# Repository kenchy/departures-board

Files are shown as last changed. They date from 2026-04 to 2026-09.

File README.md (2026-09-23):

# departures-board 

This is an ESP32 based Departures Board replicating those at many UK railway stations (using data provided by National Rail's public API), London Underground Arrivals boards (using data provided by TfL) and UK wide bus stops (using data provided by bustimes.org). This implementation uses a 3.12" OLED display panel with SSD1322 display controller onboard, plus an optional TTP223 touch sensor. STL files are also provided for 3D printing the custom desktop case. Pre-assembled departure boards are also available exclusively from our [store](https://store.gadec.co.uk).


A larger LED Matrix version of this project, with audio station announcements, is also available [here](https://github.com/gadec-uk/matrix-departures-board).

A model railway (00 gauge) version of this project is also available [here](https://github.com/gadec-uk/tiny-departures-board).

## Features
* All processing is done onboard by the ESP32 processor, no middleware servers
* Support for touch sensor to switch modes / stations / wake from screensaver
* Smooth animation matching the real departures and arrivals boards
* Displays up to the next 9 departures with scheduled time, platform number, destination, calling stations and expected departure time
* Optionally display the last reported location of a service
* Optionally only show services calling at a selected railway station
* Scheduler and Carousel modes to automatically switch between any combination of railway, tube and bus stops
* Displays Network Rail service messages
* Train information (operator, class, number of coaches etc.)
* Displays up to the next 9 arrivals with time to station (London Underground mode)
* Optionally display the current location of the train (London Underground mode)
* TfL station and network service messages (London Underground mode)
* Optionally filter by tube line and direction
* In Bus mode, displays up to the next 9 departures with service number, destination, vehicle registration and schedule/expected time
* Optionally display RSS headline feeds with UK news, sports and rail news
* RSS Feed Editor to add custom headline feeds
* Fully-featured browser based configuration screens - choose any station on the UK network / London Tube & DLR network / UK Bus Stops
* Automatic firmware updates (optional)
* Displays the weather at the selected location (optional)
* Full-screen, Network SouthEast style station clock (optional)
* STL files provided for custom 3D printed case



## Quick Start

### What you'll need

1. An ESP32 D1 Mini board (or clone) - either USB-C or Micro-USB version with CH9102 recommended. For example, from [AliExpress](https://www.aliexpress.com/item/1005005972627549.html).
2. A 3.12" 256x64 OLED Display Panel with SSD1322 display controller onboard. For example, from [AliExpress](https://www.aliexpress.com/item/1005008558326731.html).
3. A 3D printed case using the [STL](https://github.com/gadec-uk/departures-board/tree/main/stl) files provided. If you don't have a 3D printer, you can use a 3D print service, local library or group.
4. Optionally, a TTP223 touch sensor (for easily switching modes / stations). For example, from [AliExpress](https://www.aliexpress.com/item/1005007850732859.html). If fitted, the touch sensor should be glued to the inside of one of the walls of the top part of the case with the *sensor* side against the case.
5. For National Rail, the board supports using either the Rail Delivery Group feeds (recommended) or the legacy OpenLDBWS feed. Both feeds are free of charge and provide identical information but the legacy OpenLDBWS feed may be discontinued in the future. To use the Rail Delivery Group feeds, you will need a [Live Departure Board 1.1](https://raildata.org.uk/dataProduct/P-d81d6eaf-8060-4467-a339-1c833e50cbbe/overview) consumer key and (optionally) a [Service Details 1.1](https://raildata.org.uk/dataProduct/P-4dec1247-d040-4290-80a4-639dfac54a92/overview) consumer key. Alternatively, if you prefer to use the legacy OpenLDBWS feed, you can register for a token [here](https://realtime.nationalrail.co.uk/OpenLDBWSRegistration).
6. By default, weather data is sourced from Open-Meteo. If you prefer to use OpenWeather (which usually provides slightly more localised weather conditions) you will need an OpenWeather Map API token (these are also free, sign-up for a free developer account [here](https://home.openweathermap.org/users/sign_up)).
7. Some intermediate soldering skills.

A step-by-step guide to obtaining the API keys is available [here](https://departures-board.github.io/Departures-Board-API-Keys-Guide.pdf).



### Preparing the OLED display for 4-Wire SPI Mode


As supplied, the display is usually shipped with 8-bit 80XX mode enabled. This needs to be changed to 4-Wire SPI mode by removing one link and adding another (the image shows where to make these changes on the rear of the circuit board).

### Wiring Guide

Solder the 4 SPI connections, plus power and ground. The wires **MUST** be soldered to the **BACK** of the ESP32 Mini board (the side without the components) to enable it to sit in place in the case. You can solder directly to the pins on the OLED screen or for the best fit (if you are a more experienced solderer) de-solder and remove the header pins and solder directly to the board. You cannot use Dupont connectors, they will not fit the custom case design.

| OLED Pin | ESP32 Mini Pin |
|:---|:---:|
| 1 VSS | GND |
| 2 VCC_IN | 3.3v |
| 4 D0/CLK | IO18 |
| 5 D1/DIN | IO23 |
| 14 D/C# | IO5 |
| 16 CS# | IO26 |

| TTP223 Pin | ESP32 Mini Pin |
|:---|:---:|
| 1 GND | GND |
| 2 I/O | IO34 |
| 3 VCC | 3.3v |



### Installing the firmware

The project uses the Arduino framework and the ESP32 v3.3.9 core. If you want to build from source, you'll need [PlatformIO](https://platformio.org). The software is designed for, and makes use of, a dual-core ESP32 processor. If you attempt to target and compile for a single core ESP32 variant the experience will be suboptimal at best.

The easiest way to install the firmware for the first time is to use the online web based installer [here](https://departures-board.github.io). You will need to use Chrome, Edge or Firefox as your browser as Safari does not support Web Serial.

Alternatively, you can download pre-compiled firmware images from the [releases](https://github.com/gadec-uk/departures-board/releases). These can be installed over the USB serial connection using [esptool](https://github.com/espressif/esptool). If you have python installed, install with *pip install esptool*. For convenience, a pre-compiled executable version for Windows is included [here](https://github.com/gadec-uk/departures-board/tree/main/esptool).

If the board is not recognised you are probably using a version with the CP2104 USB-to-Serial chip. Drivers for the CP2104 are [here](https://www.silabs.com/developer-tools/usb-to-uart-bridge-vcp-drivers?tab=downloads)

Attach the ESP32 Mini board via it's USB port and use the following command to flash the firmware:

```
esptool.py --chip esp32 --baud 460800 write_flash -z \
  0x1000 bootloader.bin \
  0xe000 boot_app0.bin \
  0x8000 partitions.bin \
  0x10000 firmware.bin
```

The tool should automatically find the correct serial port. If it fails to, you can manually specify the correct port by adding *--port COMx* (replace *COMx* with your actual port, e.g. COM3, /dev/ttyUSB0, etc.).

If using the pre-compiled esptool.exe version on Windows, save the esptool.exe and the four firmware (.bin) files to the same directory. Open a command prompt (Windows Key + R, type cmd and press enter) and change to the directory you saved the files into. Now type the following command on one line and press enter:
```
.\esptool --chip esp32 --baud 460800 write_flash -z 0x1000 bootloader.bin 0xe000 boot_app0.bin 0x8000 partitions.bin 0x10000 firmware.bin
```

Subsequent updates can be carried out automatically over-the-air or you can manually update from the Web GUI.

### First time configuration

WiFiManager is used to setup the initial WiFi connection on first boot. The ESP32 will broadcast a temporary WiFi network named "Departures Board", connect to the network and follow the on-screen instructions. You can also watch a video walk-through of setup and configuration process below (this video shows an earlier version of the firmware, but the process is the same).
Departures Board Setup Video (https://youtu.be/PZVyE_SoLBU)

Once the ESP32 has established an Internet connection, the next step is to enter your API keys (if you do not enter a National Rail token, the board will only operate in Tube and Bus modes). Finally, select a station location. Start typing the location name and valid choices will be displayed as you type.

### Web GUI

At start-up, the ESP32's IP address is displayed. To change the station or to configure other miscellaneous settings, open the web page at that address. The settings available are:
- **Board Mode** - switch between National Rail Departures, London Underground Arrivals or UK Bus Stops modes.
- **Station** - start typing a few characters of a station name and select from the drop-down station picker displayed (National Rail mode).
- **Only show services calling at** - filter services based on *calling at* location (National Rail mode - if you want to see the next trains *to* a particular station).
- **Only show these platforms** - filter services based on the platform they depart from. Note: there are many services for which platform number is not supplied, these would also be filtered out.
- **Add to Scheduler** - adds the current configured station/tube/bus stop to the scheduler (see schedule tab) to switch based on time of day.
- **Add to Carousel** - adds the current configured station/tube/bus stop to the carousel (see schedule tab) to switch views after a period of time.
- **Underground Station** - start typing a few characters of an Underground or DLR station name and select from the drop-down station picker displayed (London Underground mode).
- **Filter by Line** - select the desired underground line or all lines for all arrivals.
- **Filter by Direction** - select the desired direction or any direction for all arrivals.
- **Bus Stop ATCO code** - type the ATCO number of the bus stop you want to monitor (see [below](#bus-stop-atco-codes) for details).
- **Only show these Bus services** - filter buses by service numbers (enter a list of the service numbers, comma separated).
- **Recently verified ATCO codes** - quickly select from recently used bus stop ATCO codes.
#### Options tab ####
- **Brightness** - adjusts the brightness of the OLED screen.
- **Show the date on screen** - displays the date in the upper-right corner (useful if you're also using this as a desk clock).
- **Show current weather at station/bus stop** - optionally display weather conditions at the selected station or bus stop.
- **Include bus replacement services** - optionally include bus replacement services (National Rail mode).
- **Show station messages** - displays station and service messages (Rail and Tube modes).
- **Show service location** - displays the current location of the next tube train that is due to arrive (Tube mode).
- **Show platform numbers if available** - deselecting this option will hide platform numbers (National Rail).
- **Show service ordinal numbers** - displays "2nd","3rd","4th" etc. next to the service times (National Rail).
- **Show service last seen location** - adds the last reported location and time of a service to the Calling at list (National Rail).
- **Wait for Calling at list to complete** - waits for the Calling at list to finish scrolling before changing the primary service.
- **Wait for Messages or RSS to complete** - waits for the current service message or RSS headline feed to finish scrolling before changing the primary service.
- **Full screen clock if no train services** - displays the full screen, Network SouthEast style station clock if there are no scheduled services at the selected railway station.
- **Enable automatic firmware updates at startup** - automatically checks for AND installs the latest firmware from this repository when the system starts up.
- **Enable daily check for firmware updates** - when enabled, the system will check for and install any updates just after midnight if the board is powered on.
- **Enable overnight sleep mode (screensaver)** - if you're running the board 24/7, you can help prevent screen burn-in by enabling this option overnight.
- **Switch off display during sleep mode** - turns off the display completely during sleep mode, otherwise displays the date & time.
- **Full screen clock during sleep mode** - displays the full screen station clock during sleep mode.
#### Schedule tab ####
- **Enable scheduler** - automatically switches between views based on the configured time of each entry in the scheduler list below.
- **Enable carousel** - automatically switches between views based on the configured view time of each entry in the carousel list below.
#### Advanced Tab ####
- **Enable touch sensor** - a tap switches between configured modes (rail/tube/bus) or wakes from sleep. If the Scheduler or Carousel mode is active, a tap switch to the next location in the list. Obviously, do not enable this option if you have not installed a TTP223 touch sensor.
- **Wake from sleep by touch for** - if the board is in screensaver mode and the touch sensor is enabled, a tap will wake the board and it will remain awake for the selected number of minutes (the countdown timer resets on each tap).
- **Long press displays full screen clock** - a long tap switches to the full screen station clock. A short tap will revert to normal operation.
- **Flip the display 180°** - Rotates the display (the case design provides two different viewing angles depending on orientation).
- **Set custom hostname for this board** - change the hostname from the default "DeparturesBoard", useful if you are running multiple boards.
- **Custom (non-UK) time zone (only for clock)** - if you're not based in the UK you can set the clock to display in your local time zone (see [below](#custom-time-zones) for details).
- **Suppress calling at / information messages** - removes all horizontally scrolling text (much lower functionality but less distracting).
- **Increase API refresh rate** - Reduces the interval between data refreshes (National Rail mode).
- **Display RSS news headlines feed** - Displays the top headlines from the selected feed (Rail/Tube mode).
- **Prioritise RSS headlines feed** - Displays headlines before other network service messages.
- **Display departures offset by** - Displays future (or past) services offset by the selected time. This does not affect the clock display (Rail mode).
- **Rail data source** - Select which api feed should be used for National Rail mode (only feeds with api keys present are shown).

A drop-down menu (top-right) adds the following options:
- **Check for Updates** - manually checks for and optionally installs any updates to the firmware. Also displays the release notes of the latest firmware.
- **Edit API Keys** - view/edit your National Rail, OpenWeather Map and Transport for London API keys.
- **Edit RSS Feeds** - loads the RSS Feeds Editor where you can add/edit/delete custom headline feeds.
- **Clear WiFi Settings** - deletes the stored WiFi credentials and restarts in WiFiManager mode (useful to change WiFi network).
- **Restart System** - restarts the ESP32.

#### Other Web GUI Endpoints

A few other urls have been implemented, primarily for debugging/developer use:
- **/factoryreset** - deletes all configuration information, api keys and WiFi credentials. The entire setup process will need to be repeated.
- **/update** - for manual firmware updates. Download the latest binary from the [releases](https://github.com/gadec-uk/departures-board/releases). Only the **firmware.bin** file should be uploaded via */update*. The other .bin files are not used for upgrades. This method is *not* recommended for normal use.
- **/info** - displays some basic information about the current running state.
- **/formatffs** - formats the filing system, erasing the configuration files (but not the WiFi credentials).
- **/dir** - displays a (basic) directory listing of the file system with the ability to view/delete files.
- **/upload** - upload a file to the file system.
- **/control** - an endpoint for automation of sleep mode. Takes optional parameters *sleep* and *clock* - e.g. /control?sleep=1&clock=0 will force sleep mode and turn off the display completely. /control?sleep=0 will revert to normal operation. Always returns current state as json.

### Bus Stop ATCO codes
Every UK bus stop has a unique ATCO code number. To find the ATCO code of the stop you want to monitor, go to [bustimes.org/search](https://bustimes.org/search) and type a location in the search box. Select the location from the list of places shown and then select the particular stop you want from the list. The ATCO code is shown on the stop information page. After entering the code in the Departures Board setup screen, tap the **Verify** button and the location will be shown confirming your selection. You must use the **Verify** button *before* you can save changes. Up to ten of the most recently verified ATCO codes are saved and can be selected from a dropdown list for quick access. The bustimes map and search facility are also embedded in the Bus mode configuration screen from firmware B2.3 onwards.



### Custom Time Zones
To set a custom time zone for the departure board clock, you will need to enter the POSIX time zone string for your location. Some examples are `CST6CDT,M3.2.0/2,M11.1.0/2` for Canada (Central Time) and `AEST-10AEDT,M10.1.0,M4.1.0/3` for Australia (Eastern Time). The easiest way to find the correct syntax is to ask your favourite AI chat engine *"What is the POSIX time zone string for ..."*. Note that changing the time zone only affects the clock (and date) display. Service times are *always* shown in UK time.

### Donating


This software is completely free for non-commercial use without obligation. If you would like to support me and encourage ongoing updates, you can [buy me a coffee!](https://buymeacoffee.com/gadec.uk)

### Licence
This work is licensed under **Creative Commons Attribution-NonCommercial-ShareAlike 4.0**. To view a copy of this licence, visit [https://creativecommons.org/licenses/by-nc-sa/4.0/](https://creativecommons.org/licenses/by-nc-sa/4.0/). Note: the terms of the licence prohibit commercial use of this work, this includes *any* reselling of the work in kit or assembled form for commercial gain.

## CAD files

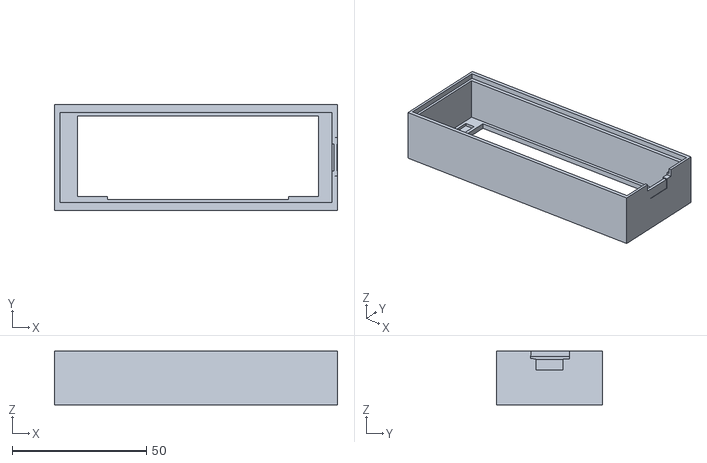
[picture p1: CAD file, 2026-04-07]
stl/Departures Board OLED Case Top Supermini.stl
105.5 x 39.7 x 20.0

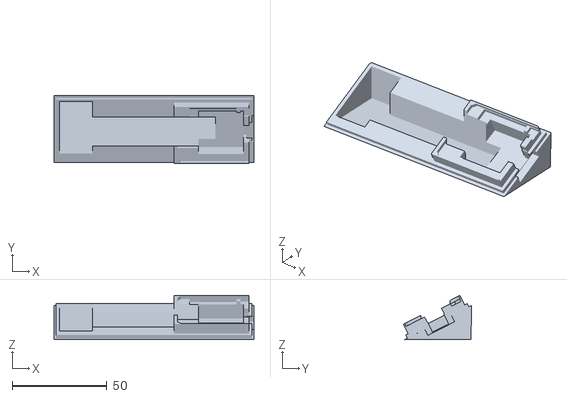
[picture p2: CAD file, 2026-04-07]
stl/Departures Board OLED Case Bottom Supermini.stl
105.5 x 36.1 x 23.4

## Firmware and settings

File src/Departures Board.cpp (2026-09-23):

/*
 * Departures Board (c) 2025-2026 Gadec Software
 *
 * https://github.com/gadec-uk/departures-board
 *
 * This work is licensed under Creative Commons Attribution-NonCommercial-ShareAlike 4.0 International.
 * To view a copy of this license, visit https://creativecommons.org/licenses/by-nc-sa/4.0/
 *
 * ESP32 "Mini" Board with 3.12" 256x64 OLED Display Panel with SSD1322 controller on-board.
 *
 * OLED PANEL     ESP32 MINI
 * 1 VSS          GND
 * 2 VCC_IN       3.3V
 * 4 D0/CLK       IO18
 * 5 D1/DIN       IO23
 * 14 D/C#        IO5
 * 16 CS#         IO26
 *
 * Optional TTP223 touch sensor connection:
 *
 * TTP223         ESP32 MINI
 * GND            GND
 * VCC            3.3V
 * I/O            IO34
 *
 */

#include <Arduino.h>
#include <WiFi.h>
#include <WiFiClientSecure.h>
#include <WiFiManager.h>
#include <AsyncTCP.h>
#include <ESPAsyncWebServer.h>
#include <StreamString.h>
#include <Ticker.h>
#include <HTTPClient.h>
#include <ESPmDNS.h>
#include <HTTPUpdateGitHub.h>
#include <FS.h>
#include <LittleFS.h>
#include <ArduinoJson.h>
#include <weatherClient.h>
#include <sharedDataStructs.h>
#include <responseCodes.h>
#include <raildataXmlClient.h>
#include <rdmRailClient.h>
#include <TfLdataClient.h>
#include <busDataClient.h>
#include <githubClient.h>
#include <rssClient.h>
#include <touchSensor.h>
#include <webgui/webgraphics.h>
#include <webgui/index.h>
#include <webgui/keys.h>
#include <webgui/editrss.h>
#include <webgui/rss.h>
#include <gfx/xbmgfx.h>
#include <time.h>

#include <SPI.h>
#include <U8g2lib.h>

#define msDay 86400000 // 86400000 milliseconds in a day
#define msHour 3600000 // 3600000 milliseconds in an hour
#define msMin 60000 // 60000 milliseconds in a second

static AsyncWebServer server(80); // Hosting the Web GUI

// Shorthand for response formats
static const char contentTypeJson[] = "application/json";
static const char contentTypeText[] = "text/plain";
static const char contentTypeHtml[] = "text/html";

// Using NTP to set and maintain the clock
static struct tm timeinfo;
static const char ukTimezone[] = "GMT0BST,M3.5.0/1,M10.5.0";

// Default hostname
static const char defaultHostname[] = "DeparturesBoard";

// Local firmware updates via /update Web GUI
static const char updatePage[] =
"<script src='https://ajax.googleapis.com/ajax/libs/jquery/3.2.1/jquery.min.js'></script>"
"<html><body style=\"font-family:Helvetica,Arial,sans-serif\"><h2>Departures Board Manual Update</h2><p>Upload a <b>firmware.bin</b> file.</p>"
"<form method='POST' action='#' enctype='multipart/form-data' id='upload_form'>"
   "<input type='file' name='update'>"
        "<input type='submit' value='Update'>"
    "</form>"
 "<div id='prg'>progress: 0%</div>"
 "<script>"
  "$('form').submit(function(e){"
  "e.preventDefault();"
  "var form = $('#upload_form')[0];"
  "var data = new FormData(form);"
  " $.ajax({"
  "url: '/update',"
  "type: 'POST',"
  "data: data,"
  "contentType: false,"
  "processData:false,"
  "xhr: function() {"
  "var xhr = new window.XMLHttpRequest();"
  "xhr.upload.addEventListener('progress', function(evt) {"
  "if (evt.lengthComputable) {"
  "var per = evt.loaded / evt.total;"
  "$('#prg').html('Progress: ' + Math.round(per*100) + '%');"
  "}"
  "}, false);"
  "return xhr;"
  "},"
  "success:function(d, s) {"
  "console.log('success!')"
 "},"
 "error: function (a, b, c) {"
 "}"
 "});"
 "});"
 "</script></body></html>";

// /upload page
static const char uploadPage[] =
"<html><body style=\"font-family:Helvetica,Arial,sans-serif\">"
"<h2>Upload a file to the file system</h2><form method='post' enctype='multipart/form-data'><input type='file' name='name'>"
"<input class='button' type='submit' value='Upload'></form></body></html>";

// /success page
static const char successPage[] =
"<html><body style=\"font-family:Helvetica,Arial,sans-serif\"><h3>Upload completed successfully.</h3>\n"
"<p><a href=\"/dir\">List file system directory</a></p>\n"
"<h2>Upload another file</h2><form method=\"post\" action=\"/upload\" enctype=\"multipart/form-data\"><input type=\"file\" name=\"name\"><input class=\"button\" type=\"submit\" value=\"Upload\"></form>\n"
"</body></html>";

#define SCREEN_WIDTH 256 // OLED display width, in pixels
#define SCREEN_HEIGHT 64 // OLED display height, in pixels
#define DIMMED_BRIGHTNESS 1 // OLED display brightness level when in sleep/screensaver mode

//U8G2_SSD1322_NHD_256X64_F_4W_HW_SPI u8g2(U8G2_R0, /* cs=*/ GPIO_NUM_26, /* dc=*/ GPIO_NUM_5, /* reset=*/ U8X8_PIN_NONE);
U8G2_SSD1322_NHD_256X64_F_4W_HW_SPI u8g2(U8G2_R0, /* cs=*/ 8, /* dc=*/ 9, /* reset=*/ U8X8_PIN_NONE);

// Vertical line positions on the OLED display (National Rail)
#define LINE0 0
#define LINE1 13
#define LINE2 28
#define LINE3 41
#define LINE4 55

// Vertical line positions on the OLED display (Underground)
#define ULINE0 0
#define ULINE1 15
#define ULINE2 28
#define ULINE3 41
#define ULINE4 56

static Ticker restartTimer; // used to schedule reboots

//
// Custom fonts - replicas of those used on the real display boards
//
static const uint8_t NatRailSmall9[1329] U8G2_FONT_SECTION("NatRailSmall9") =
  "\221\0\3\2\4\4\4\5\5\11\11\0\0\11\0\11\2\1E\2\214\5\30 \5\0\230)!\7q("
  "%\6%\42\10\63h)\22K\0#\17u(mJI\62(\225A)%\11\0$\14u(\255\262"
  "\245\266%\311\26\1%\14t(+\42E\212\244H\221\2&\16u(m\244\222\224$R\22EJ\0"
  "'\6\61h%\6(\11s(\251\222R\255\0)\11s()\262R\245\4*\12U\70-\222\312b"
  "Y\32+\12U\70\255\302h\220\302\10,\7\62\10g\22\5-\6\23X)\6.\6\21(%\2/"
  "\13t(\353\42)\222\42)\3\60\12u(m\226\314[\262\0\61\11s)m\22\251\313\0\62\13u"
  "(m\226,\314\332\6\1\63\14u(m\226,\214T-Y\0\64\15u(\355\62))%\203\26&"
  "\0\65\13u(-\216C\32j\311\2\66\15u(m\226L\34\222LK\26\0\67\12u(-\6\61"
  "+\66\1\70\15u(m\226LK\226LK\26\0\71\15u(m\226LK\206PK\26\0:\7A"
  "\70%\242\0;\7R(gR\5<\10t(\353\242\306\6=\10\64H+\206p\10>\11t(+"
  "\302\246\66\0?\14u(m\226,\214\264\34\212\0@\14u(m\226\314\222(C\272\0A\13u("
  "m\226L\33\206\314\26B\15u(-\206$\323\6%\323\6\5C\13u(m\226LlK\26\0D"
  "\13u(-\206$\363\66(\0E\13u(-\216\341\220\204\341 F\13u(-\216\341\220\204E\0"
  "G\15u(m\226LL\206LK\26\0H\13u(-\62\333\60d\266\0I\7q(%\16\1J"
  "\11u(-;j\311\2K\15u(-\62))iIT\311\2L\11u(-\302\36\7\1M\13"
  "u(-\262eI\64\267\0N\13u(-\262II\244\315\26O\12u(m\226\314[\262\0P\14"
  "u(-\206$\323\6%,\2Q\13\225\10m\226\314[\62\246\1R\15u(-\206$\323\6\245T"
  "\311\2S\13u(m\226L]\265d\1T\11u(-\6)\354\11U\11u(-\62\337\222\5V"
  "\12u(-\62oI-\2W\13u(-\62\227DIn\1X\14u(-\62-\251UjZ\0"
  "Y\13u(-\62-\251\205M\0Z\12u(-\6\61\353\70\10[\10r('\226.\2\134\12t"
  "(+\62-\323\62-]\10r(\63\224.\3^\6#xi\32_\7\24\30+\206\0`\7\42x"
  "'\242\0a\12U(m\326d\320\222!b\13u(-\302\212I\323\6\5c\11U(m\6\261:"
  "\4d\13u(-+\246MK\206\0e\12U(m\226l\30\322!f\12t(\253*\245)+\1"
  "g\14u\10m\6\315\226\14\341\240\0h\12u(-\302\212I\263\5i\7q(%\222Aj\13\224"
  "\10\353r k\223\22\5k\13t(+\262\222\222HI)l\7q(%\16\1m\12U(m\272"
  "(\211\246\5n\11U(-\22\223f\13o\12U(m\226\314\226,\0p\14u\10-\206$\263\15"
  "J\30\2q\13u\10m\6\315\226\14a\1r\11U(-\22\223X\4s\11U(m\6\365\240\0"
  "t\13t(k\262hH\262\242\0u\11U(-\62'E\11v\12U(-\62[R\213\0w\14"
  "U(-\62%Q\22\245\13\0x\12U(-\262\244V\251\5y\13u\10-\62\267d\10\7\5z"
  "\11U(-\6\255m\20{\12s(\251\222(\311\242,|\7q(%\16\1}\13s()\262("
  "K\242$\2~\10%XmL\11\0\15u(-\222\254R\214\222(Q\12\200\5\0\10!\201\14"
  "e)\361\222A\213\262A\311\0\202\10B\10g*\12\0\203\5\0\10!\204\11D\10kzQ\22\0"
  "\205\7\25(-\222\2\206\15v(o\206$\64\16\17I\224\0\207\16w(\261\266\244)\262\250I\226"
  "M\0\210\21\210\30\63\323!\213\222d\213\262\245\224\15i\10\211\5\0\10!\212\5\0\10!\213\5\0"
  "\10!\214\5\0\10!\215\15u(/NK\242)C\62\14\2\216\16u(/\16\221\62(\203\42\15"
  "C\0\217\14w(\61\336\246\310\242n\303\1\220\6\63N?\36\221\7\62h'\222(\222\7\62hg"
  "\22\5\223\10\64h+\222\246$\224\10\64hkZ\224\4\225\6\63H)\36\226\7\25X-\6\1\227"
  "\5\0\10!\230\5\0\10!\231\5\0\10!\232\5\0\10!\233\5\0\10!\234\5\0\10!\235\5\0"
  "\10!\236\5\0\10!\237\5\0\10!\240\5\0\10!\241\5\0\10!\242\5\0\10!\243\14u(\255"
  "\244J\66Da\66\10\244\5\0\10!\245\5\0\10!\246\5\0\10!\247\5\0\10!\250\5\0\10!"
  "\251\5\0\10!\252\5\0\10!\253\5\0\10!\254\5\0\10!\255\5\0\10!\256\5\0\10!\257\5"
  "\0\10!\260\12DXk\224HJ\24\0\0\0\0";

static uint8_t NatRailTall12[1102] U8G2_FONT_SECTION("NatRailTall12") =
  "c\0\3\2\4\4\2\5\5\11\14\0\375\11\375\11\0\1Q\2\235\4\65 \5\0f\12!\7\221B"
  "\211C\22\42\7#^\212D\11#\21\225B\233R\222\14J)\211\222dPJI\2$\17\225B\253"
  "l)%\331\226DI\262E\0%\12\225B\313i\312:\35\1&\20\225B\33\251\22%Q$%\211"
  "\224D\221\22'\6!^\11\1(\11\223B\252\244\324\255\0)\11\223B\212\254\324\245\4*\14uF"
  "\253Je\261,M\21\0+\12UJ\253\60\32\244\60\2,\7\62\272\231D\1-\6\23R\212\1."
  "\6!B\11\1/\11\225B\313\266\216E\0\60\12\225B\233%\363[\262\0\61\11\223C\233D\352\313"
  "\0\62\13\225B\233%\13k\35\7\1\63\15\225B\233%\13Kj\250%\13\0\64\16\225B\273LJ"
  "JI\224\14ZX\1\65\15\225B\213c\70\244a\250%\13\0\66\15\225B\233%\23\303!\311l\311"
  "\2\67\15\225B\213A\254\205Y\230\205\31\0\70\15\225B\233%\263%KfK\26\0\71\15\225B\233"
  "%\263%C\30j\311\2:\6QJ\11E;\10b\306\231Z\242\0<\10t\306\272\250\261\1=\10"
  "\64\316\212!\34\2>\10t\306\212\260\251\15?\14\225B\233%\13k\305\34\212\0@\16\225B\233%"
  "\263$J\242\14a\272\0A\13\225B\233%\263\15C\346\26B\15\225B\213!\311l\203\222\331\6\5"
  "C\13\225B\233%\23{K\26\0D\13\225B\213!\311\374\66(\0E\13\225B\213cqH\302\342"
  " F\13\225B\213cqH\302F\0G\14\225B\233%\23K\233-Y\0H\13\225B\213\314m\30"
  "\62\267\0I\6\221B\211\7J\11\225B\313>j\311\2K\16\225B\213\60\223\222\222\246%Q%\13"
  "L\11\225B\213\260\37\7\1M\14\225B\213lY\22%\321\274\5N\15\225B\213l\232\224DI\244"
  "\233\26O\12\225B\233%\363[\262\0P\14\225B\213!\311l\203\22\66\2Q\13\265:\233%\363["
  "\62\246\1R\16\225B\213!\311l\203R\252dZ\0S\14\225B\233%S\325\242\226,\0T\11\225"
  "B\213A\12\373\11U\11\225B\213\314\337\222\5V\12\225B\213\314oI-\2W\13\225B\213\314\227"
  "DIn\1X\16\225B\213LKJIV\211\222\232\26Y\14\225B\213LKJI\26v\2Z\13"
  "\225B\213A\254u\14\7\1[\10\222\302\211\245/\2\134\11\225B\213\260\332\261\0]\10\222\302\11\245"
  "/\3^\6#^\232\6_\6\25>\213A`\6\42\336\211(a\13eB\233\65\31\64-\31\2b"
  "\14\225B\213\260\305\244i\223\242\0c\11eB\233Al\35\2d\13\225B\313\26\323fR\224\0e"
  "\14eB\233%\33\206\60K\26\0f\13\224\302*%\213\206$\353\4g\15\225\66\33\323fR\224P"
  "K\26\0h\12\225B\213\260\305\244\271\5i\7\201B\211d\30j\13\264\266\272\34\310z\223\22\5k"
  "\15\225B\213\260))iIT\311\2l\6\221B\211\7m\15eB\13\245EI\224DI\224\2n"
  "\11eB\213\304\244\271\5o\12eB\233%sK\26\0p\15\225\66\213\304\244i\223\242\204E\0q"
  "\13\225\66\33\323fR\224\260\1r\11eB\213\304$\66\2s\12eB\233%]\265d\1t\12\204"
  "\302\232,\32\222\254Qu\11eB\213\314\223\242\4v\14eB\213LKJI\26F\0w\16eB"
  "\213$Q\22%Q\22\245\13\0x\13eB\213,\251\205YR\13y\14\225\66\213\314\223\242\204Z\262"
  "\0z\12eB\213A\314\332\6\1{\21\227B\234,\321\226\245\247\310\242&Y\222,\1|\6\221B"
  "\213\7}\17\266\66\273\70\31\306:\26\206\303\22g\0~\21\226\302\233!\31\206P\34\36\24e\30\222"
  "(\1\16\226\302\213$\314\224(\315\222,\351?\200\24\231B\255AK\223L\222B)\224BMJ"
  "\322l\220\0\201\24\231>\255AK\223,\323\62-\323\26\35H\322l\220\0\202\22\231>\335t\320*"
  "\311\30\245Q\270\324\262AM\1\0\0\0";

static const uint8_t NatRailClockSmall7[137] U8G2_FONT_SECTION("NatRailClockSmall7") =
  "\12\0\3\3\3\3\3\1\5\7\7\0\0\7\0\7\0\0\0\0\0\0p\60\12?\343Td\274I*"
  "\0\61\10\274\343HF\272\20\62\13?\343TdRIE*=\63\14?\343TdR\331\230&\251\0"
  "\64\14?\343\315H\22%\311Q*\1\65\13?c\34\244f)MR\1\66\14?\343TdT\213\214"
  "&\251\0\67\11?c\134\205Z\325\0\70\15?\343Td\64IEF\223T\0\71\14?\343Td\64"
  "\211\225&\251\0\0\0\0";

static const uint8_t NatRailClockLarge9[177] U8G2_FONT_SECTION("NatRailClockLarge9") =
  "\13\0\4\3\4\4\3\2\5\11\11\0\0\11\0\11\0\0\0\0\0\0\230\60\13\231T\307\205\24\277\222"
  "\270\0\61\11\224W\207\304\210\276 \62\16\231T\307\205\224\234\212\13\71u\7\2\63\17\231T\307\205\224"
  "\234\232B\71*\211\13\0\64\23\231T\327\24\221\204\214\210\32\11!\211\3\61\71\11\0\65\20\231T\307"
  "\301\234\334A\240\34\25\225\304\5\0\66\20\231T\307\205\24\235\334A\204\24+\211\13\0\67\14\231T\303"
  "\201\234\252Ur\32\1\70\17\231T\307\205\24+\211\13)V\22\27\0\71\20\231T\307\205\24+\211\203"
  "\70\71*\211\13\0:\7r\235\2\31\1\0\0\0";

static const uint8_t Underground10[1335] U8G2_FONT_SECTION("Underground10") =
  "\221\0\3\2\3\4\4\5\5\11\12\0\377\11\377\11\0\1^\2\310\5\36 \5\0\314\25!\7I\204"
  "\22\207$\42\7\23\274\24\211\22#\21M\204\66\245$\31\224R\22%\311\240\224\222\4$\17M\204V"
  "\331RJ\262-\211\222d\213\0%\12M\204\226\323\224u:\2&\17F\204\67Z\324\246E\211\226D"
  "I\42\5'\10\42\254\23C\242\0(\10J\204\63J\237\2)\11J\204\23Q\322\213\2*\14=\214"
  "V\225\312AY\232\42\0+\12-\224Va\64Ha\4,\10\42|\23C\242\0-\7\15\244\26\203"
  "\0.\7\22\204\23C\0/\10?\214\327i\237\1\60\14N\204\67C\22\372\61\31\22\0\61\7J\205"
  "\67K?\62\14N\204\67C\22\246\305\216\303\0\63\16N\204\67C\22\246\245\71\25\223!\1\64\16N"
  "\204\227\241\226D\225,\31\306\264\2\65\16N\204\27\207\64\35\344\64\25\223!\1\66\17N\204\67C\22"
  "\252\351\240\204\306dH\0\67\12N\204\27\327b\257)\0\70\17N\204\67C\22\32\223!\11\215\311\220"
  "\0\71\17N\204\67C\22\32\223AM\305dH\0:\10\62\214\23C\70\4;\11:\204\23C\250("
  "\0<\10<\214uQc\3=\10\34\234\25C\70\4>\11<\214\25aS\33\0?\15M\204\66K"
  "\246\205Y\61\207\42\0@\16M\204\66KfI\224D\31\302t\1A\14N\204\67C\22\32\207At"
  "\14B\16N\204\27\203\22\32\207%\64\16\13\0C\14N\204\67C\22\252=&C\2D\13N\204\27"
  "\203\22\372qX\0E\14N\204\27\207\264:\14iu\30F\14N\204\27\207\264:\14i+\0G\16"
  "N\204\67C\22\252\225A\64&C\2H\13N\204\27\241\343\60\210\216\1I\11K\204\24K\324\227\1"
  "J\12M\204\226=jZ\262\0K\20N\204\27\241\226D\225LL\262\250\226\204\1L\11N\204\27i"
  "\277\16\3M\16O\204\30\351\266T\244H\212T\327\0N\15N\204\27\241\270)\221\224h\243\61O\14"
  "N\204\67C\22\372\61\31\22\0P\14N\204\27\203\22\32\207%m\5Q\14V|\67C\22\372)I"
  "\206\70R\16N\204\27\203\22\32\207\245\26\325\222\60S\17N\204\67C\22\252\361\20\247b\62$\0T"
  "\12O\204\30\207,\356\67\0U\12N\204\27\241?&C\2V\14O\204\30\251\257IVI\63\0W"
  "\16O\204\30\251\247H\212\244H\351\226\0X\16O\204\30\251\232d\225\264\222UR\65Y\14O\204\30"
  "i\222U\322\270\67\0Z\13O\204\30\207\70\355\363\60\4[\10J\204\23K_\4\134\11M\204\26a"
  "\265c\1]\10J\204\23J_\6^\6\23\274\64\15_\7\15|\26\203\0`\7\42\254\23\203\24a"
  "\13\65\214\66k\62hZ\62\4b\14E\214\26a\70$\231\333\240\0c\12\65\214\66K&\326\222\5"
  "d\13E\214\226\225AsK\206\0e\14\65\214\66K\66\14a\226,\0f\13L\204UJ\26MY"
  "'\0g\14E|\66K\346\226\14a\262\0h\13M\204\26a\70$\231o\1i\7A\214\22\311\60"
  "j\11S|Ti\324\323\2k\15E\214\26a))iIT\311\2l\10C\214\24Q\337\4m\16"
  "\67\214\30\213\22ER$ER$\25n\11\65\214\26C\222y\13o\12\65\214\66K\346\226,\0p"
  "\14E|\26C\222\271\15J\30\2q\13E|\66K\346\226\14a\1r\12\64\214\25\311\20em\0"
  "s\12\65\214\66K\272j\311\2t\13D\214\65Y\64$Y\243\0u\11\65\214\26\231\267d\10v\12"
  "\65\214\26\231[R\213\0w\13\67\214\30\251S\244tK\0x\13\65\214\26YR\13\263\244\26y\13"
  "E|\26\231\267d\10\7\5z\12\65\214\26\203V\314\262A{\13K\204TIT\311\242Z\0|\6"
  "I\204\26\17}\13K\204\24YTK\242J\4~\21N\204\67C\62\14\241\70<(\312\60$Q\2"
  "\16N\204\27I\230)Q\232%Y\322\200\5\0\204\20\201\10\25\204\26I\242\24\202\5\0\204\20"
  "\203\5\0\204\20\204\5\0\204\20\205\5\0\204\20\206\5\0\204\20\207\5\0\204\20\210\5\0\204\20\211\5"
  "\0\204\20\212\5\0\204\20\213\5\0\204\20\214\5\0\204\20\215\5\0\204\20\216\5\0\204\20\217\5\0\204"
  "\20\220\6\33\237\37\17\221\5\0\204\20\222\5\0\204\20\223\5\0\204\20\224\5\0\204\20\225\5\0\204\20"
  "\226\5\0\204\20\227\5\0\204\20\230\5\0\204\20\231\5\0\204\20\232\5\0\204\20\233\5\0\204\20\234\5"
  "\0\204\20\235\5\0\204\20\236\5\0\204\20\237\5\0\204\20\240\5\0\204\20\241\5\0\204\20\242\5\0\204"
  "\20\243\14=\214VR%\33\242\60\33\4\244\5\0\204\20\245\5\0\204\20\246\5\0\204\20\247\5\0\204"
  "\20\250\5\0\204\20\251\5\0\204\20\252\5\0\204\20\253\5\0\204\20\254\5\0\204\20\255\5\0\204\20\256"
  "\5\0\204\20\257\5\0\204\20\260\12-\244\66KfK\26\0\0\0\0";

static const uint8_t UndergroundClock8[150] U8G2_FONT_SECTION("UndergroundClock8") =
  "\13\0\3\3\3\4\2\2\5\7\10\0\0\10\0\10\0\0\0\0\0\0}\60\12G\305\251\310\370&\251"
  "\0\61\10\304\305\222\234\364\0\62\15G\305\251\310\244B\331L(;\10\63\15G\305\251\310\244\42\62\215"
  "&\251\0\64\15G\305\24\316H\22%\311Q*\1\65\14G\305\70\310\250f\32MR\1\66\14G\305"
  "\251\310\250\26\31\233\244\2\67\12G\305\70\310\204z\225\2\70\15G\305\251\310h\222\212\214MR\1\71"
  "\15G\305\251\310h\22+\215&\251\0:\6\262\257 \22\0\0\0";

// Service attribution texts
static const char nrAttributionn[] = "Powered by National Rail Enquiries";
static const char rdgAttribution[] = "Powered by Rail Delivery Group";
static const char btAttribution[] = "Powered by bustimes.org";

#define SCREENSAVERINTERVAL 8000      // How often the screen is changed in sleep mode (ms - 8 seconds)
#define DATAUPDATEINTERVAL 90000      // How often we fetch data from National Rail (ms - 1.5 mins) - "default" option
#define FASTDATAUPDATEINTERVAL 45000  // How often we fetch data from National Rail (ms - 45 secs) - "fast" option
#define UGDATAUPDATEINTERVAL 30000    // How often we fetch data from TfL (ms - 30 secs)
#define BUSDATAUPDATEINTERVAL 45000   // How often we fetch data from bustimes.org (ms - 45 secs)
#define RSSUPDATEINTERVAL 600000      // How often to refresh the RSS feed (ms - 10 mins)
#define WEATHERUPDATEINTERVAL 1200000 // How often to update the weather forecast (ms - 20 mins)

// Reusable data transfer structures
rdiStation xfrStation;
stnMessages xfrMessages;
busTubeStation xfrBusTubeStation;
sharedBufferSpace jsonKeyBuffer;
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
void loop(void) {

  if (touchEnabled) button.updateTouchState();

  if (button.wasShortTapped()) {
    if (isSleeping) {
      if (NSEclockIsActive) NSEclockIsActive = false;
      else forcedAwake = true;
    } else {
      switchToNextMode();
    }
  } else if (button.wasLongTapped() && longPressClock) {
    NSEclockIsActive = !NSEclockIsActive;
  }

  if (millis()-lastTimeUpdate >= 100) {
    // Update the current time
    int prevSecond = timeinfo.tm_sec;
    if (getLocalTime(&timeinfo)) {
      sprintf(currentTime,"%02d:%02d:%02d",timeinfo.tm_hour,timeinfo.tm_min,timeinfo.tm_sec);
      lastTimeUpdate = millis();
      if (millis()>3888000000 && timeinfo.tm_hour==3) ESP.restart(); // Reboot every 45 days at 3am
      if (isSleeping && (useNSEclockForSleep || NSEclockIsActive) && prevSecond != timeinfo.tm_sec) drawNSEclock();  // Update the large clock
    }
  }

  // Check for firmware updates daily if enabled
  if (dailyUpdateCheck && !fetchInProgress && millis()>fwUpdateCheckTimer) {
    fwUpdateCheckTimer = millis() + 3300000 + random(600000); // check again in 55 to 65 mins
    if (timeinfo.tm_mday != prevUpdateCheckDay) {
      if (ghUpdate.getLatestRelease()==UPD_SUCCESS) {
        checkForFirmwareUpdate();
      }
      prevUpdateCheckDay = timeinfo.tm_mday;
    }
  }

  bool wasSleeping = isSleeping;
  isSleeping = isSnoozing();

  if (isSleeping && !useNSEclockForSleep && !NSEclockIsActive && millis()>timer) {       // If the "screensaver" is active, change the screen every 8 seconds
    drawSleepingScreen();
    timer=millis() + SCREENSAVERINTERVAL;
  } else if (wasSleeping && !isSleeping) {
    // Exit sleep mode cleanly
    softResetBoard(MODE_LOADCONFIG);
  } else if (isSleeping && !wasSleeping && useNSEclockForSleep && !NSEclockIsActive) u8g2.setContrast(DIMMED_BRIGHTNESS);

  // WiFi Status icon
  if (WiFi.status() != WL_CONNECTED && wifiConnected) {
    wifiConnected=false;
    u8g2.setFont(NatRailSmall9);
    u8g2.drawStr(0,56,"\x7F");  // No Wifi Icon
    u8g2.updateDisplayArea(0,7,1,1);
  } else if (WiFi.status() == WL_CONNECTED && !wifiConnected) {
    wifiConnected=true;
    blankArea(0,57,5,7);
    u8g2.updateDisplayArea(0,7,1,1);
    updateMyUrl();  // in case our IP changed
  }

  // Force a manual reset if we've been disconnected for more than 10 secs
  if (WiFi.status() != WL_CONNECTED && millis() > lastWiFiReconnect+10000) {
    WiFi.disconnect();
    delay(100);
    WiFi.reconnect();
    lastWiFiReconnect=millis();
  }

  switch (boardMode) {
    case MODE_RAIL:
      departureBoardLoop();
      break;

    case MODE_TUBE:
      undergroundArrivalsLoop();
      break;

    case MODE_BUS:
      busDeparturesLoop();
      break;
  }

  if (manualUpdateCheck && !fetchInProgress) doManualOtaCheck();

  if (rssEnabled && boardMode != MODE_BUS && millis() > nextRssUpdate && !fetchInProgress && !isSleeping && wifiConnected) {
    // Start an RSS Update on Core 0
    fetchMode = FETCH_RSS;
    fetchInProgress = true;
    xTaskNotifyGive(fetchTaskHandle);
  }

  if (rssFetchComplete) {
    // Background fetch has completed
    rssFetchComplete = false;
    if (lastRssUpdateResult == UPD_SUCCESS) buildRssMessage();
  }

  if (weatherEnabled && millis()>nextWeatherUpdate && !fetchInProgress && locationLat && locationLon && !isSleeping && wifiConnected) {
    // Start a weather update on Core 0
    fetchMode = FETCH_WEATHER;
    fetchInProgress = true;
    xTaskNotifyGive(fetchTaskHandle);
  }

  if (weatherFetchComplete) {
    weatherFetchComplete = false;
    if (lastWeatherUpdateResult == UPD_SUCCESS) {
      strlcpy(weatherMsg,currentWeather.currentWeatherMessage,MAXWEATHERSIZE);
    } else {
      weatherMsg[0] = '\0';
    }
  }

  if (softResetNeeded && !fetchInProgress) {
    softResetNeeded=false;
    softResetBoard(MODE_LOADCONFIG);
  }

  if ((schedulerActive || (carouselActive && numCarouselSlots>1)) && !isSleeping && !fetchInProgress && millis() > nextSchedulerCheck) {
    int nowTime = getTimeInMinutes();
    if ((activeSlotEventTime < nextSlotEventTime && nowTime >= nextSlotEventTime) || (activeSlotEventTime > nextSlotEventTime && nowTime < activeSlotEventTime && nowTime >= nextSlotEventTime)) {
      if (carouselActive) currentCarouselSlot = (currentCarouselSlot + 1) % numCarouselSlots;
      softResetBoard(MODE_LOADCONFIG);
    }
    nextSchedulerCheck = millis() + 10000;  // ten seconds
  }

}

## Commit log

2026-03-15 B2.3-W3.0 updates
    Version B2.3-W3.0 includes the following changes:
    - Support for TPP223 Touch Sensor (or push button) to switch modes / stations / wake from sleep.
    - RSS Feeds Editor to add/edit/delete custom headline feeds.
    - Switched to asynchronous web server for improved GUI performance (particularly on mobile devices).
    - Upgraded web interface to Bootstrap 5.
    - Fixed bug with National Rail library that caused occasional "no data" errors.
    - Other small bug fixes / code cleaning.
2026-03-24 Change environment from esp32dev to esp32-c3-devkitm-1
    change the .ini so it targets an esp32 c3 supermini
2026-03-24 Change GPIO pins for ESP32 C3 Super Mini
    Updated GPIO pin assignments for ESP32 C3 Super Mini and modified touch sensor connection.
2026-04-07 added new stl for supermini
    [Departures Board OLED Case Bottom Supermini.stl, Departures Board OLED Case Top Supermini.stl]
2026-06-23 B3.4-W.3.4 Updates
    Version B3.4-W3.4 includes the following changes:
    Adds a full-screen, Network SouthEast style station clock. New options enable the clock to be displayed whenever no services are available at the selected railway station, during "sleep" hours and by a long-press on the touch sensor.
    In Bus mode, more data is now retrieved when necessary to display departures further into the future (particularly when filtering stops with many services).
    In Rail mode, the missing bus icon has been restored for bus services.
    Moved to version 3.3.9 of the ESP32 platform. Other minor bug fixes.
    [Departures Board.cpp]
2026-07-13 B3.5-W3.4 Updates
    Version B3.5-W3.4 is a minor maintenance release. No new features are included.
    - Fixes an issue with possible screen corruption with the option to display the full screen NSE clock when no services are available.
    - Improves performance of the legacy Darwin Lite data feed.
    [Departures Board.cpp]
2026-08-14 B3.6-W3.4 updates
    Version B3.6-W3.4 is a maintenance release. No new features are included.
    - Fixes an issue with the legacy National Rail Darwin client.
    - Other minor bug fixes.
    [Departures Board.cpp]
2026-08-30 B3.7-W3.4 Update
    Version B3.7-W3.4 is a maintenance release. No new features are included.
    - Corrects the sort order of bus services when displaying multiple days
    - Displays correct eta in the calling stations list for delayed services
    - Displays the correct calling stations list for services with early termination
    - Fixed a bug that could cause no services to be found in rare circumstances
    - Improved firmware update notice explanation display
    - Other minor improvements and fixes
    [Departures Board.cpp]

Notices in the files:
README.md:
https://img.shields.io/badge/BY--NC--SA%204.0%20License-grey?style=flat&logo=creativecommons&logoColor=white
